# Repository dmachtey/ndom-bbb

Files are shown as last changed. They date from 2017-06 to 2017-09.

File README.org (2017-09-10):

* High density BBB domotic cape.
  - 32 opto inputs +32 opto outputs for BeagleBone Black
  - this board is intended to be used for domotics or whatever you
    want.
  - It has Push-in spring's connectors for easiness and space reduction
  - All inputs and outputs are gated though =GPIO3_15=
  - There are two more boards on this project:
    - "relay-board" is a single relay board.
    - "out-board" is a high current (10A) Mosfet Board intended for
      (soft) PWM LEDs, up to 60 volts

#+ATTR_LaTeX: :width 10cm\textwidth :options angle=0 :placement [H]
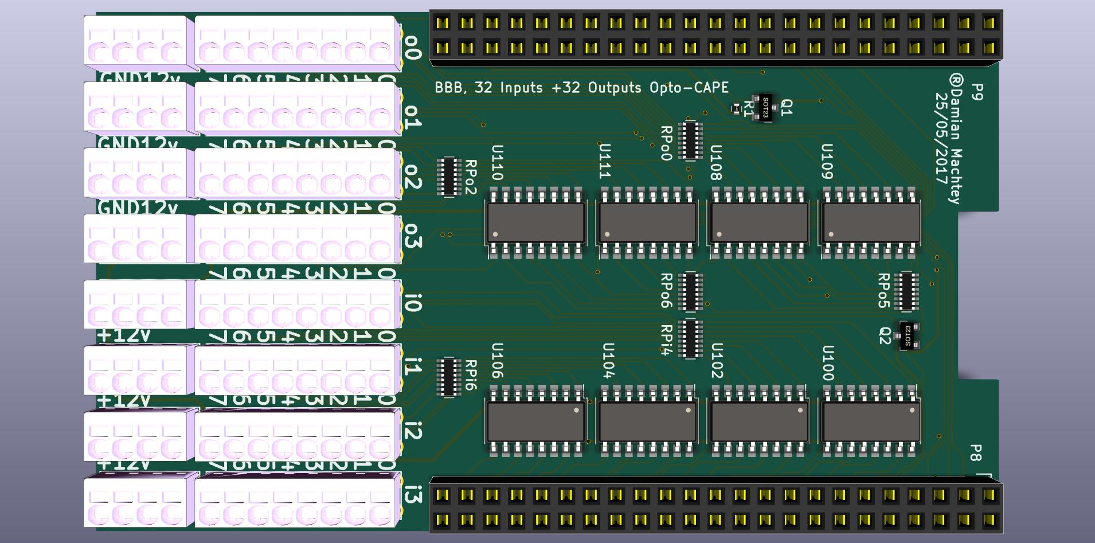
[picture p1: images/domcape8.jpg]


* Contact information
  - Damian Machtey
  - dmachtey at gmail com
* License
  - Hardware is released under [[http://creativecommons.org/licenses/by-sa/4.0/][Creative Commons Sharealike 4.0
    International]]
    
  - Software is released under GNU General Public License
    http://www.gnu.org/licenses/
  - © 2017 Damian Machtey

* Fell free to use this project
  - Just please let me know
  - and if you manufacture the board please keep my name on it.

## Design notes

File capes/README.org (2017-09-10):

* To be able to use all the 65 gpio you need to:

** Disable some capes

edit /boot/uEnv.txt and add:
#+BEGIN_EXAMPLE
         optargs=quietcapemgr.disable_partno=BB-BONELT-HDMI,BB-BONELT-HDMIN,BB-BONE-EMMC-2G
#+END_EXAMPLE

Reboot, and

if it works: you should see some thing like this:

#+BEGIN_EXAMPLE
   root@beaglebone:~# SLOTS=/sys/devices/bone_capemgr.9/slots
   root@beaglebone:~# cat $SLOTS
    0: 54:PF---
    1: 55:PF---
    2: 56:PF---
    3: 57:PF---
    4: ff:P-O-- Bone-LT-eMMC-2G,00A0,Texas Instrument,BB-BONE-EMMC-2G
    5: ff:P-O-- Bone-Black-HDMI,00A0,Texas Instrument,BB-BONELT-HDMI
    6: ff:P-O-- Bone-Black-HDMIN,00A0,Texas Instrument,BB-BONELT-HDMIN
#+END_EXAMPLE
and ther should be no "L"  before the capes lines

** Load the new cape
As an example

#+BEGIN_SRC sh
    SLOTS=/sys/devices/bone_capemgr.9/slots
    echo GPIOS-dommach > $SLOTS
#+END_SRC

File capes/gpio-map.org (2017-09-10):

# Description:
# Author: Damian Machtey
#
# Created: Tue Sep  5 15:23:36 2017 (-0300)
#
# Last-Updated: Fri Sep  8 10:53:05 2017 (-0300)
#           By: Damian Machtey
#
#

        | Address  Mode   | BBB Port | gpio number | Slot | Order | gpio     | Modee 7 | Mode | Mode    | Comment |   |   |
        |-----------------+----------+-------------+------+-------+----------+---------+------+---------+---------+---+---|
        | 0x194  0x07  // | P9_29    |         111 | -    |     - | GPIO3_15 | SPI     |      | BoardEn |         |   |   |
        | 0x038  0x27  // | P8_16    |          46 | i4   |     0 | GPIO1_14 |         |      |         |         |   |   |
        | 0x08c  0x27  // | P8_18    |          65 | i4   |     1 | GPIO2_1  |         |      |         |         |   |   |
        | 0x084  0x27  // | P8_20    |          63 | i4   |     2 | GPIO1_31 | UART4   |      |         |         |   |   |
        | 0x014  0x27  // | P8_22    |          37 | i4   |     3 | GPIO1_5  |         |      |         |         |   |   |
        | 0x010  0x27  // | P8_23    |          36 | i4   |     4 | GPIO1_4  |         |      |         |         |   |   |
        | 0x000  0x27  // | P8_25    |          32 | i4   |     5 | GPIO1_0  |         |      |         |         |   |   |
        | 0x0E0  0x27  // | P8_27    |          86 | i4   |     6 | GPIO2_22 |         |      |         |         |   |   |
        | 0x0E4  0x27  // | P8_29    |          87 | i4   |     7 | GPIO2_23 |         |      |         |         |   |   |
        | 0x0EC  0x27  // | P8_30    |          89 | i5   |     0 | GPIO2_25 |         |      |         |         |   |   |
        | 0x0E8  0x27  // | P8_28    |          88 | i5   |     1 | GPIO2_24 |         |      |         |         |   |   |
        | 0x07c  0x27  // | P8_26    |          61 | i5   |     2 | GPIO1_29 |         |      |         |         |   |   |
        | 0x004  0x27  // | P8_24    |          33 | i5   |     3 | GPIO1_1  |         |      |         |         |   |   |
        | 0x080  0x27  // | P8_21    |          62 | i5   |     4 | GPIO1_30 | UART4   |      |         |         |   |   |
        | 0x020  0x27  // | P8_19    |          22 | i5   |     5 | GPIO0_22 |         |      |         |         |   |   |
        | 0x02c  0x27  // | P8_17    |          27 | i5   |     6 | GPIO0_27 |         |      |         |         |   |   |
        | 0x03c  0x27  // | P8_15    |          47 | i5   |     7 | GPIO1_15 |         |      |         |         |   |   |
        | 0x0A0  0x27  // | P8_45    |          70 | i6   |     0 | GPIO2_6  |         |      |         |         |   |   |
        | 0x0A8  0x27  // | P8_43    |          72 | i6   |     1 | GPIO2_8  |         |      |         |         |   |   |
        | 0x0B4  0x27  // | P8_42    |          75 | i6   |     2 | GPIO2_11 |         |      |         |         |   |   |
        | 0x0BC  0x27  // | P8_40    |          77 | i6   |     3 | GPIO2_13 |         |      |         |         |   |   |
        | 0x0C0  0x27  // | P8_37    |          78 | i6   |     4 | GPIO2_14 |         |      |         |         |   |   |
        | 0x0C8  0x27  // | P8_36    |          80 | i6   |     5 | GPIO2_16 |         |      |         |         |   |   |
        | 0x0CC  0x27  // | P8_34    |          81 | i6   |     6 | GPIO2_17 |         |      |         |         |   |   |
        | 0x0DC  0x27  // | P8_32    |          11 | i6   |     7 | GPIO0_11 |         |      |         |         |   |   |
        | 0x0A4  0x27  // | P8_46    |          71 | i7   |     0 | GPIO2_7  |         |      |         |         |   |   |
        | 0x0AC  0x27  // | P8_44    |          73 | i7   |     1 | GPIO2_9  |         |      |         |         |   |   |
        | 0x0B0  0x27  // | P8_41    |          74 | i7   |     2 | GPIO2_10 |         |      |         |         |   |   |
        | 0x0B8  0x27  // | P8_39    |          76 | i7   |     3 | GPIO2_12 |         |      |         |         |   |   |
        | 0x0C4  0x27  // | P8_38    |          79 | i7   |     4 | GPIO2_15 |         |      |         |         |   |   |
        | 0x0D0  0x27  // | P8_35    |           8 | i7   |     5 | GPIO0_8  |         |      |         |         |   |   |
        | 0x0D4  0x27  // | P8_33    |           9 | i7   |     6 | GPIO0_9  |         |      |         |         |   |   |
        | 0x0D8  0x27  // | P8_31    |          10 | i7   |     7 | GPIO0_10 |         |      |         |         |   |   |
        | 0x00c  0x07  // | P8_06    |          35 | o0   |     0 | GPIO1_3  |         |      |         |         |   |   |
        | 0x008  0x07  // | P8_05    |          34 | o0   |     1 | GPIO1_2  |         |      |         |         |   |   |
        | 0x01c  0x07  // | P8_04    |          39 | o0   |     2 | GPIO1_7  |         |      |         |         |   |   |
        | 0x018  0x07  // | P8_03    |          38 | o0   |     3 | GPIO1_6  |         |      | ??      |         |   |   |
        | 0x028  0x07  // | P8_14    |          26 | o0   |     4 | GPIO0_26 |         |      |         |         |   |   |
        | 0x024  0x07  // | P8_13    |          23 | o0   |     5 | GPIO0_23 |         |      |         |         |   |   |
        | 0x030  0x07  // | P8_12    |          44 | o0   |     6 | GPIO1_12 |         |      |         |         |   |   |
        | 0x034  0x07  // | P8_11    |          45 | o0   |     7 | GPIO1_13 |         |      |         |         |   |   |
        | 0x070  0x07  // | P9_11    |          30 | o1   |     0 | GPIO0_30 |         |      |         |         |   |   |
        | 0x078  0x07  // | P9_12    |          60 | o1   |     1 | GPIO1_28 |         |      |         |         |   |   |
        | 0x074  0x07  // | P9_13    |          31 | o1   |     2 | GPIO0_31 |         |      |         |         |   |   |
        | 0x048  0x07  // | P9_14    |          50 | o1   |     3 | GPIO1_18 |         |      |         |         |   |   |
        | 0x098  0x07  // | P8_10    |          68 | o1   |     4 | GPIO2_4  |         |      |         |         |   |   |
        | 0x09c  0x07  // | P8_09    |          69 | o1   |     5 | GPIO2_5  |         |      |         |         |   |   |
        | 0x094  0x07  // | P8_08    |          67 | o1   |     6 | GPIO2_3  |         |      |         |         |   |   |
        | 0x090  0x07  // | P8_07    |          66 | o1   |     7 | GPIO2_2  |         |      |         |         |   |   |
        | 0x198  0x07  // | P9_30    |         112 | o2   |     0 | GPIO3_16 | SPI     |      |         |         |   |   |
        | 0x190  0x07  // | P9_31    |         110 | o2   |     1 | GPIO3_14 | SPI     |      |         |         |   |   |
        | 0x1b4  0x07  // | P9_41    |          20 | o2   |     2 | GPIO0_20 |         |      |         |         |   |   |
        | 0x164  0x07  // | P9_42    |           7 | o2   |     3 | GPIO0_7  |         |      |         |         |   |   |
        | 0x158  0x07  // | P9_18    |           4 | o2   |     4 | GPIO0_4  | I2C1    |      |         |         |   |   |
        | 0x15c  0x07  // | P9_17    |           5 | o2   |     5 | GPIO0_5  | I2C1    |      |         |         |   |   |
        | 0x04c  0x07  // | P9_16    |          51 | o2   |     6 | GPIO1_19 |         |      |         |         |   |   |
        | 0x040  0x07  // | P9_15    |          48 | o2   |     7 | GPIO1_16 |         |      |         |         |   |   |
        | 0x184  0x07  // | P9_24    |          15 | o3   |     0 | GPIO0_15 | UART1   | I2C1 |         |         |   |   |
        | 0x044  0x07  // | P9_23    |          49 | o3   |     1 | GPIO1_17 |         |      |         |         |   |   |
        | 0x150  0x07  // | P9_22    |           2 | o3   |     2 | GPIO0_2  | UART2   | I2C2 |         |         |   |   |
        | 0x154  0x07  // | P9_21    |           3 | o3   |     3 | GPIO0_3  | UART2   | I2C2 |         |         |   |   |
        | 0x19c  0x07  // | P9_28    |         113 | o3   |     4 | GPIO3_17 | SPI     |      |         |         |   |   |
        | 0x1a4  0x07  // | P9_27    |         115 | o3   |     5 | GPIO3_19 |         |      |         |         |   |   |
        | 0x180  0x07  // | P9_26    |          14 | o3   |     6 | GPIO0_14 | UART1   | I2C1 |         |         |   |   |
        | 0x1ac  0x07  // | P9_25    |         117 | o3   |     7 | GPIO3_21 |         |      |         |         |   |   |

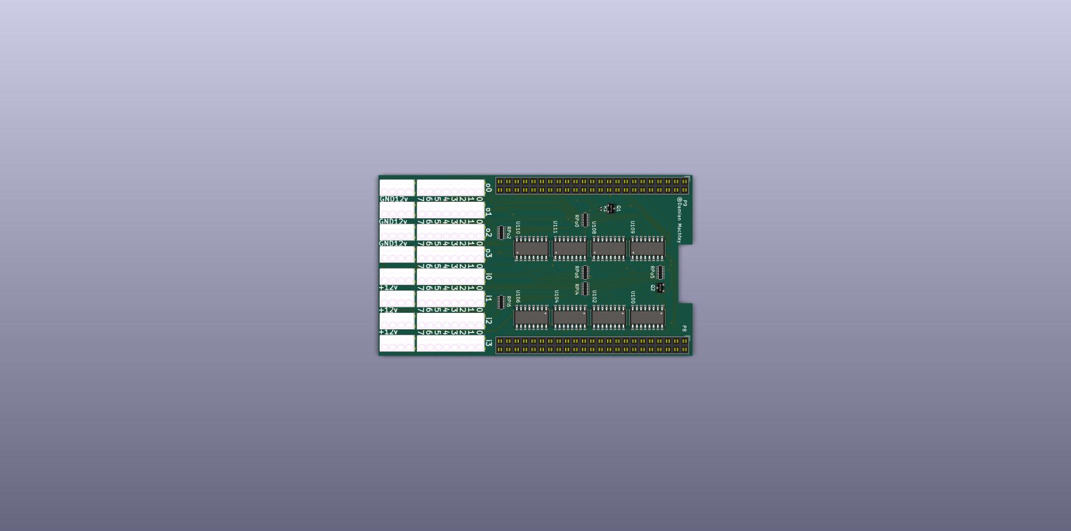
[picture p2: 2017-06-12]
images/domcape6.jpg

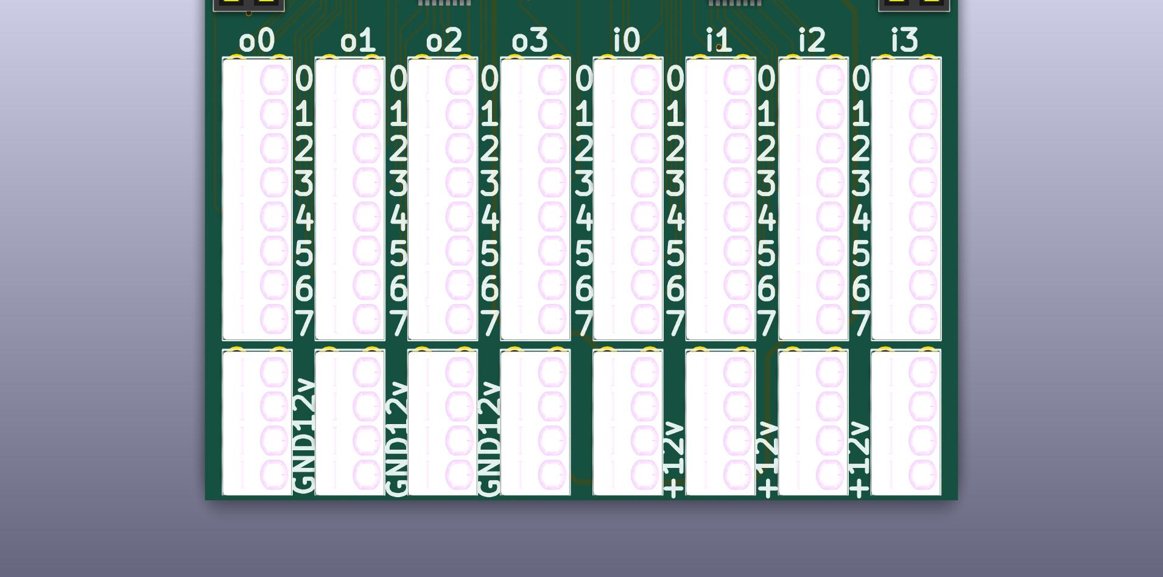
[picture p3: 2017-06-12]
images/domcape5.jpg

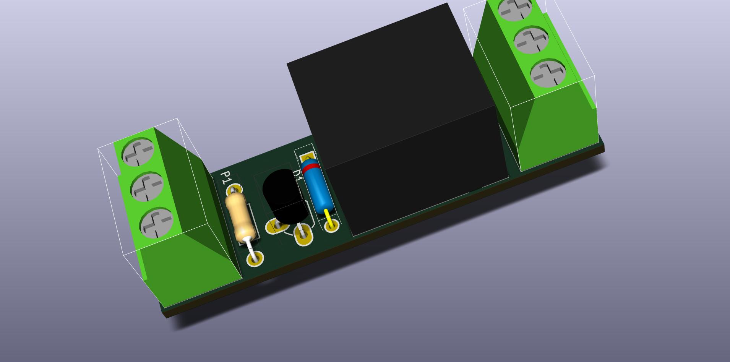
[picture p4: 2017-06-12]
images/relay-board.jpg

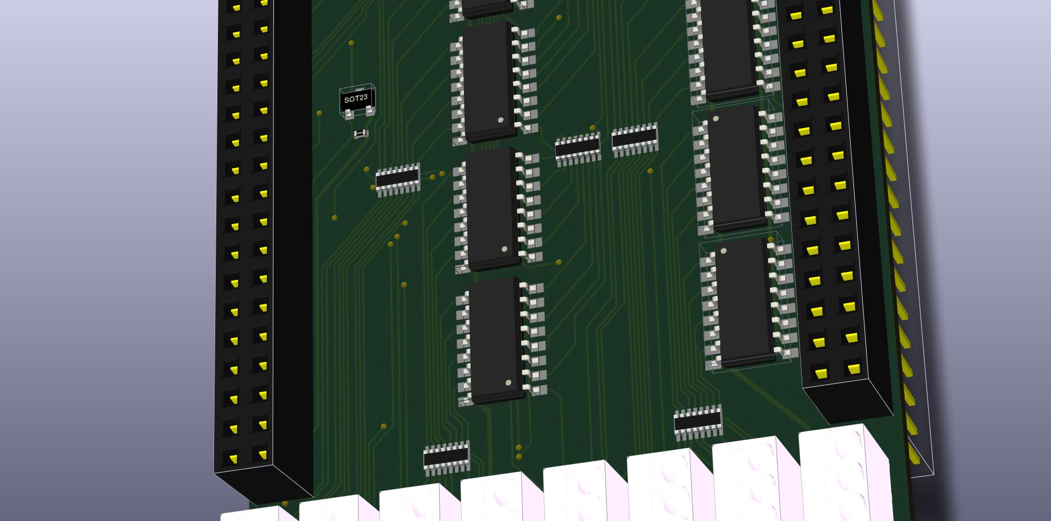
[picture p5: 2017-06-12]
images/domcape4.jpg

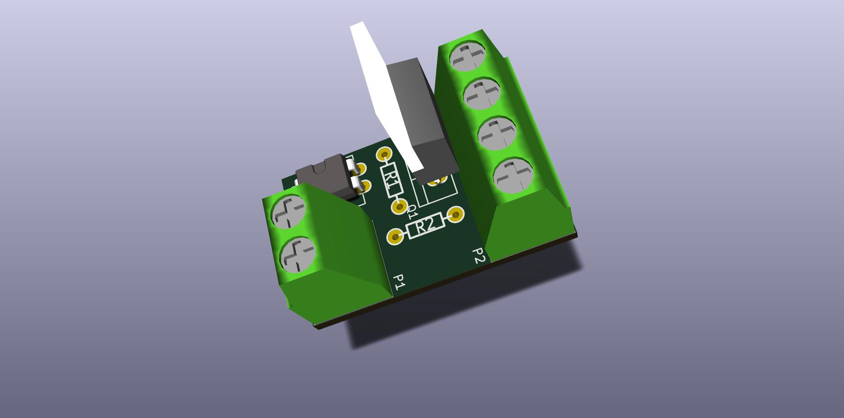
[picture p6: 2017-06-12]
images/out-board.jpg

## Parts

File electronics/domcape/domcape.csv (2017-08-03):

Reference | Value | Footprint | Datasheet
R1 | 1000G | Resistors_SMD:R_0402
P9 | BeagleBone_Black_Header
P8 | BeagleBone_Black_Header
RPo5 | MNR18ERAPJ152 | Resistors_SMD:R_Array_Convex_8x0602 | http://rohmfs.rohm.com/en/products/databook/datasheet/passive/resistor/chip_resistor_network/mnr_g.pdf
RPo6 | MNR18ERAPJ152 | Resistors_SMD:R_Array_Convex_8x0602
RPo7 | MNR18ERAPJ152 | Resistors_SMD:R_Array_Convex_8x0602
RPo8 | MNR18ERAPJ152 | Resistors_SMD:R_Array_Convex_8x0602
Px0 | Ph-1770979 | Connectors_Phoenix:Phoenix_PTSM05_4-2.5_thr
Px1 | Ph-1770979 | Connectors_Phoenix:Phoenix_PTSM05_4-2.5_thr
Px2 | Ph-1770979 | Connectors_Phoenix:Phoenix_PTSM05_4-2.5_thr
Px3 | Ph-1770979 | Connectors_Phoenix:Phoenix_PTSM05_4-2.5_thr
Px4 | Ph-1770979 | Connectors_Phoenix:Phoenix_PTSM05_4-2.5_thr
Px5 | Ph-1770979 | Connectors_Phoenix:Phoenix_PTSM05_4-2.5_thr
Px6 | Ph-1770979 | Connectors_Phoenix:Phoenix_PTSM05_4-2.5_thr
Px7 | Ph-1770979 | Connectors_Phoenix:Phoenix_PTSM05_4-2.5_thr
Po0 | Phoenix-1771017 | Connectors_Phoenix:Phoenix_PTSM05_8-2.5_thr | http://www.phoenixcontact.com/us/products/1771017/pdf
Po4 | Phoenix-1771017 | Connectors_Phoenix:Phoenix_PTSM05_8-2.5_thr | http://www.phoenixcontact.com/us/products/1771017/pdf
Po1 | Phoenix-1771017 | Connectors_Phoenix:Phoenix_PTSM05_8-2.5_thr | http://www.phoenixcontact.com/us/products/1771017/pdf
Po2 | Phoenix-1771017 | Connectors_Phoenix:Phoenix_PTSM05_8-2.5_thr | http://www.phoenixcontact.com/us/products/1771017/pdf
Po3 | Phoenix-1771017 | Connectors_Phoenix:Phoenix_PTSM05_8-2.5_thr | http://www.phoenixcontact.com/us/products/1771017/pdf
Po5 | Phoenix-1771017 | Connectors_Phoenix:Phoenix_PTSM05_8-2.5_thr | http://www.phoenixcontact.com/us/products/1771017/pdf
Po6 | Phoenix-1771017 | Connectors_Phoenix:Phoenix_PTSM05_8-2.5_thr | http://www.phoenixcontact.com/us/products/1771017/pdf
Po7 | Phoenix-1771017 | Connectors_Phoenix:Phoenix_PTSM05_8-2.5_thr | http://www.phoenixcontact.com/us/products/1771017/pdf
Q2 | SQ2303ES | Housings_SOT-23_SOT-143_TSOT-6:SOT-23 | https://www.vishay.com/docs/67023/sq2303es.pdf
Q1 | SQ2348ES | Housings_SOT-23_SOT-143_TSOT-6:SOT-23 | http://www.vishay.com/docs/63706/sq2348es.pdf
U100 | TLP291-4 | Housings_SSOP:SOP-16_4.4x10.4mm_Pitch1.27mm | http://www.mouser.com/ds/2/408/TLP291-4-204553.pdf
U101 | TLP291-4 | Housings_SSOP:SOP-16_4.4x10.4mm_Pitch1.27mm
U102 | TLP291-4 | Housings_SSOP:SOP-16_4.4x10.4mm_Pitch1.27mm
U103 | TLP291-4 | Housings_SSOP:SOP-16_4.4x10.4mm_Pitch1.27mm
U104 | TLP291-4 | Housings_SSOP:SOP-16_4.4x10.4mm_Pitch1.27mm
U105 | TLP291-4 | Housings_SSOP:SOP-16_4.4x10.4mm_Pitch1.27mm
U106 | TLP291-4 | Housings_SSOP:SOP-16_4.4x10.4mm_Pitch1.27mm
U107 | TLP291-4 | Housings_SSOP:SOP-16_4.4x10.4mm_Pitch1.27mm
U108 | TLP291-4 | Housings_SSOP:SOP-16_4.4x10.4mm_Pitch1.27mm
U109 | TLP291-4 | Housings_SSOP:SOP-16_4.4x10.4mm_Pitch1.27mm
U110 | TLP291-4 | Housings_SSOP:SOP-16_4.4x10.4mm_Pitch1.27mm
U111 | TLP291-4 | Housings_SSOP:SOP-16_4.4x10.4mm_Pitch1.27mm
U112 | TLP291-4 | Housings_SSOP:SOP-16_4.4x10.4mm_Pitch1.27mm
U113 | TLP291-4 | Housings_SSOP:SOP-16_4.4x10.4mm_Pitch1.27mm
U114 | TLP291-4 | Housings_SSOP:SOP-16_4.4x10.4mm_Pitch1.27mm
U115 | TLP291-4 | Housings_SSOP:SOP-16_4.4x10.4mm_Pitch1.27mm
RPi7 | YC248-JR-074K7L | Resistors_SMD:R_Array_Convex_8x0602
RPi6 | YC248-JR-074K7L | Resistors_SMD:R_Array_Convex_8x0602
RPi4 | YC248-JR-074K7L | Resistors_SMD:R_Array_Convex_8x0602
RPi5 | YC248-JR-074K7L | Resistors_SMD:R_Array_Convex_8x0602
RPo0 | YC248-JR-074K7L | Resistors_SMD:R_Array_Convex_8x0602
RPo1 | YC248-JR-074K7L | Resistors_SMD:R_Array_Convex_8x0602
RPo2 | YC248-JR-074K7L | Resistors_SMD:R_Array_Convex_8x0602
RPo3 | YC248-JR-074K7L | Resistors_SMD:R_Array_Convex_8x0602

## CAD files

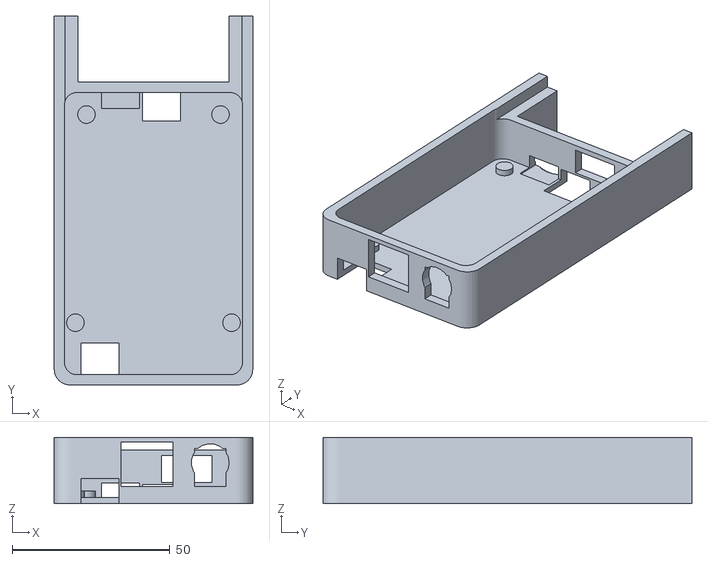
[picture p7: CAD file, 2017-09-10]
case/BBB-ndom-case.stl
63.0 x 117.0 x 21.0

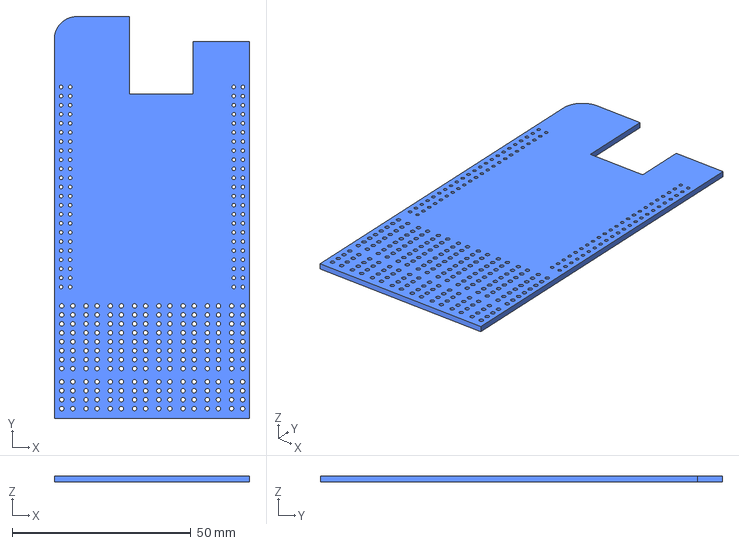
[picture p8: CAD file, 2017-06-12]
electronics/domcape/domcape.step
54.6 x 112.3 x 1.60 mm

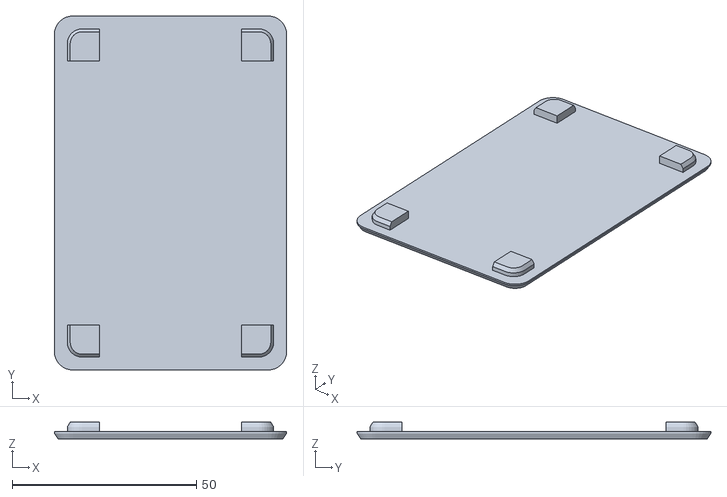
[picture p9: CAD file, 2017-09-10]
case/BeagleBoneBlack-lid.stl
63.0 x 96.0 x 4.50

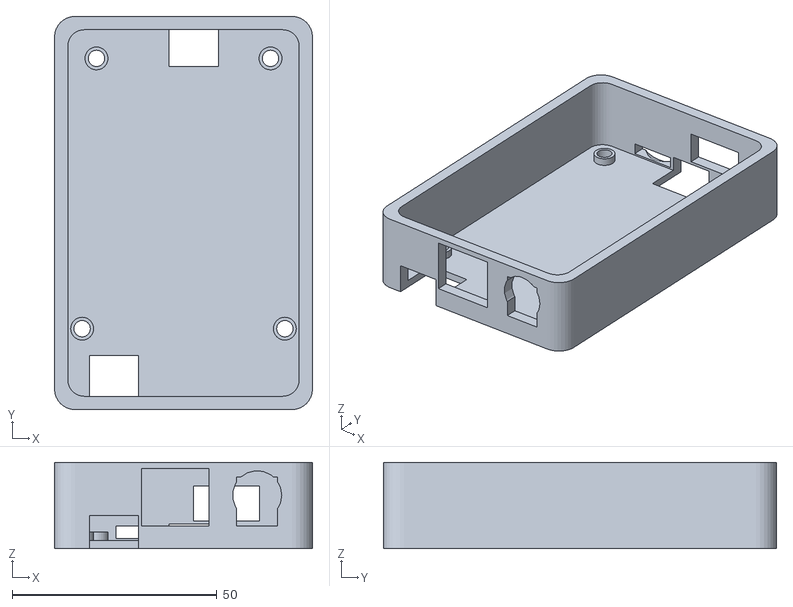
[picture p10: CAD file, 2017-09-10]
case/BeagleBoneBlack-case.stl
63.0 x 96.0 x 21.0

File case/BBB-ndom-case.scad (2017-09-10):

wall_thickness=6.5;
base_thickness=2.0;
bb_depth=20;
bb_width=56.5;
bb_height=89.5;
bb_curve_corner=10;

peg_pow_front=16.5;
peg_pow_side=3.5;

peg_sd_front=7;
peg_sd_side=7;

peg_outer_radius=2.8;
peg_inner_radius=2.0;

module RoundedBB(extra_width,extra_height,depth,curve=bb_curve_corner) {
          minkowski() {
               cube([bb_width-curve+extra_width,bb_height-curve+extra_height,depth],center=true);
               cylinder(r=curve/2, height=depth, $fn=32);
          }
}

module BeagleBox(curve=bb_curve_corner) {
     union () {
     difference() {
          RoundedBB(wall_thickness, wall_thickness, bb_depth, curve);
          translate([0,0,base_thickness])
               RoundedBB(0, 0, bb_depth, curve-2);
     }
     translate([0,55+2.5,0.5])
            cube([bb_width+wall_thickness,23,bb_depth+1],center=true);

     // wall corrections
     translate([bb_width/2+wall_thickness/2-1.5,40,0.5])
          cube([3,23,bb_depth+1],center=true);

     translate([-bb_width/2-wall_thickness/2+1.5,40,0.5])
          cube([3,23,bb_depth+1],center=true);
     }
}

difference() {
     union() {
          difference() {
               BeagleBox();

               translate([0,0,-bb_depth/2+9]) {
                    // -- Bottom End --

                    // Power connector
                    %				translate([18,-bb_height/2,2.5])
                         cube([10,10,12],center=true);
                    translate( [18,-45,4] )
                         rotate( [90,0,0] )
                         cylinder( r=6, h=9, center=true );
                    translate([18,-bb_height/2,2.5])
                         cube([10,10,12],center=true);
                    // Ethernet port
                    translate([-2,-bb_height/2,3.5])
                         cube([16.5,10,14],center=true);

                    // Mini USB (Underneath)
                    // translate([-23,-bb_height/2-5,-16])     // protruding
                    // translate([-23,-bb_height/2,-9+0.334])  // thin layer underneath
                    //	cube([10,12,base_thickness-0.3333]);
                    translate([-23,-bb_height/2-10,-10])
                         cube([12,20,9]);
                    // original mini USB, doesn't fit cable
                    % translate([-22,-bb_height/2-10,-12])
                           cube([10,20,8]);

                    // -- Top reduction Damian--
                    translate([-56/2,40,8.01-1])
                           cube([56,30,17-12]);

                    // -- End reduction
                    translate([-48/2,47.9,-11])
                         cube([48,22,20]);


                    // SD Card slot
                    translate([-6.5-4,bb_height/2,-5.0])
                         cube([12,10,5], center=true); // was 3 in z
                    // Original SD slot
                    %				translate([-6.5,bb_height/2,-5.5])
                                         cube([12,10,2], center=true);
                    // thumb depression for inserting card
                    translate([-6.5-4,bb_height/2+3.5,-5.0])
                         scale( [1,2.3,0.5] )
                         rotate( [90,0,0] )
                         cylinder( r1=7, r2=0, h=6 );
                    // HDMI port
                    translate([-6.5+3.0,bb_height/2-9,-12.0])
                         cube([12,20,9]);
                    // USB port
                    translate([10.5,bb_height/2,2.0])
                         cube([16,10,8.5],center=true);
               }
          }

          // Pegs
          translate([0,0,-bb_depth/2+9]) {
               // Pegs on "power" end
               translate([-bb_width/2+peg_pow_side,-bb_height/2+peg_pow_front,-6])
                    cylinder(r=peg_outer_radius,h=2,$fn=32,center=true);
               translate([bb_width/2-peg_pow_side,-bb_height/2+peg_pow_front,-6])
                    cylinder(r=peg_outer_radius,h=2,$fn=32,center=true);

               // Pegs on "sd card" end
               translate([-bb_width/2+peg_sd_side,bb_height/2-peg_sd_front,-6])
                    cylinder(r=peg_outer_radius,h=2,$fn=32,center=true);
               translate([bb_width/2-peg_sd_side,bb_height/2-peg_sd_front,-6])
                    cylinder(r=peg_outer_radius,h=2,$fn=32,center=true);
          }
     }
     // Drill holes through pegs and floor
//	translate([0,0,-bb_depth/2+9]) {
     // Pegs on "power" end
//		translate([-bb_width/2+peg_pow_side,-bb_height/2+peg_pow_front,-5])
//			cylinder(r=peg_inner_radius,h=10,$fn=32,center=true);
//		translate([bb_width/2-peg_pow_side,-bb_height/2+peg_pow_front,-5])
//			cylinder(r=peg_inner_radius,h=10,$fn=32,center=true);

     // Pegs on "sd card" end
//		translate([-bb_width/2+peg_sd_side,bb_height/2-peg_sd_front,-5])
//			cylinder(r=peg_inner_radius,h=10,$fn=32,center=true);
//		translate([bb_width/2-peg_sd_side,bb_height/2-peg_sd_front,-5])
//			cylinder(r=peg_inner_radius,h=10,$fn=32,center=true);
//	}
}

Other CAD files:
case/BeagleBoneBlack-case.scad
case/BeagleBoneBlack-lid.scad
electronics/domcape/domcape.FCStd

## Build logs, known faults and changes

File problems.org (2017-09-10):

# Description:
# Author: Damian Machtey
#
# Created: Sat Sep  9 12:22:26 2017 (-0300)
#
# Last-Updated: Sun Sep 10 13:53:06 2017 (-0300)
#           By: Damian Machtey
#
#

* some problems found on the board as [2017-09-09 Sat]

#+BEGIN_EXAMPLE
    root@beaglebone:~/ndom-bbb/board-test# ./board-test.py
      i0 i1 i2 i3
    0  0  0  0  0
    1  0  0  0  0
    2  1  0  0  0
    3  1  1  0  0
    4  1  1  0  0
    5  1  0  0  0
    6  0  0  0  0
    7  0  0  0  0

      a0 a1 a2 a3
    0  0  0  0  0
    1  0  0  0  0
    2  0  0  0  0
    3  0  0  0  0
    4  0  0  0  0
    5  0  0  0  0
    6  0  0  0  0
    7  0  0  0  0
#+END_EXAMPLE

    - as shown above some inputs remain high when nothing is
      connected, not even the cape. It looks like the pull-down
      resistor is not enough for some pins

      - P8_20
      - P8_21
      - P8_22
      - P8_23
      - P8_24
      - P8_25

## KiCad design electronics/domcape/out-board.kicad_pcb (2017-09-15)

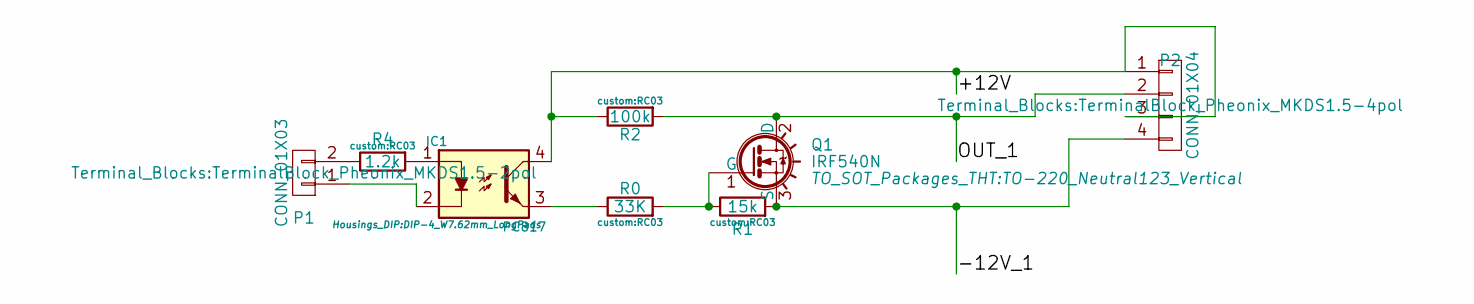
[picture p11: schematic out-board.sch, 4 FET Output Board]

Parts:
IC1: PC817; DIP-4_W7.62mm_LongPads
P1: CONN_01X03; TerminalBlock_Pheonix_MKDS1.5-2pol
P2: CONN_01X04; TerminalBlock_Pheonix_MKDS1.5-4pol
Q1: IRF540N; TO-220_Neutral123_Vertical
R0: 33K; RC03
R1: 15k; RC03
R2: 100k; RC03
R4: 1.2k; RC03

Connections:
/+12V: IC1.4, P2.1, P2.3, R2.1
/-12V_1: P2.4, Q1.3 (S), R1.2
/OUT_1: P2.2, Q1.2 (D), R2.2
unnamed: IC1.1, R4.2
unnamed: IC1.2, P1.1
unnamed: IC1.3, R0.1
unnamed: P1.2, R4.1
unnamed: Q1.1 (G), R0.2, R1.1

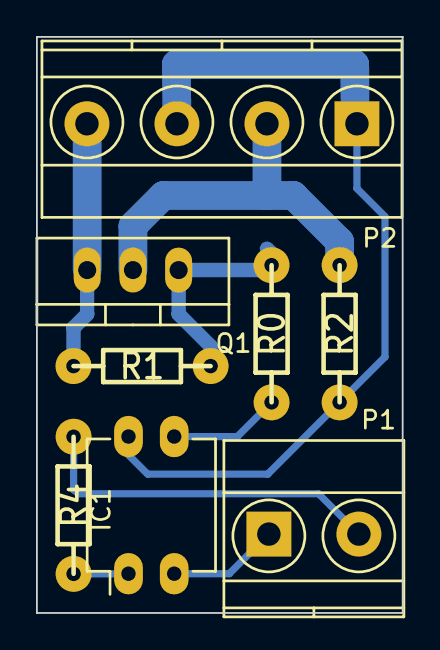
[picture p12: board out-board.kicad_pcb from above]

Board: 2 copper layers, 20.3 x 32.0 mm, 8 parts (0 on the bottom side), 8 nets.

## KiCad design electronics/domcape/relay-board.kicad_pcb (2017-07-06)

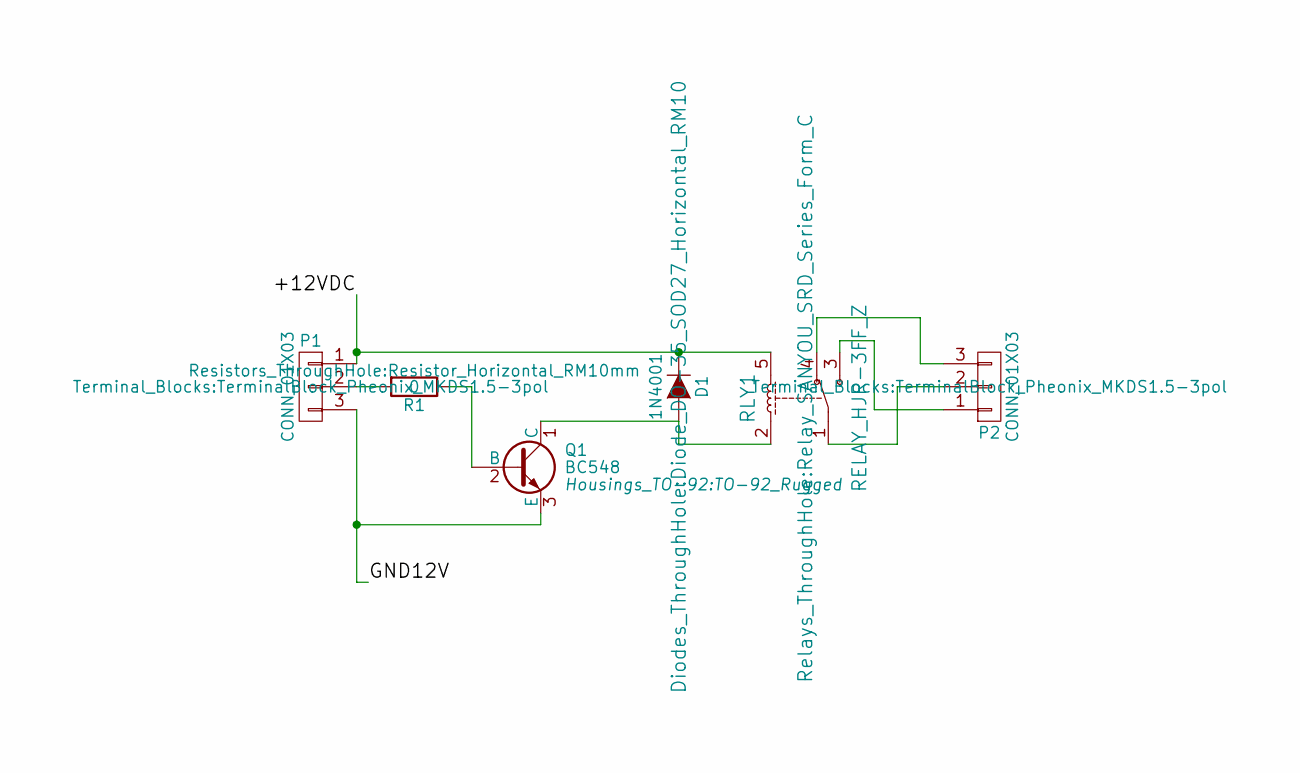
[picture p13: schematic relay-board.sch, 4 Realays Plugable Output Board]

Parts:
D1: 1N4001; Diode_DO-35_SOD27_Horizontal_RM10
P1, P2: CONN_01X03; TerminalBlock_Pheonix_MKDS1.5-3pol
Q1: BC548; TO-92_Rugged
R1: 0; Resistor_Horizontal_RM10mm
RLY1: RELAY_HJR-3FF_Z; Relay_SANYOU_SRD_Series_Form_C

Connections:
/+12VDC: D1.1 (K), P1.1, RLY1.5
/GND12V: P1.3, Q1.3 (E)
unnamed: D1.2 (A), Q1.1 (C), RLY1.2
unnamed: P1.2, R1.2
unnamed: P2.1, RLY1.3
unnamed: P2.2, RLY1.1
unnamed: P2.3, RLY1.4
unnamed: Q1.2 (B), R1.1

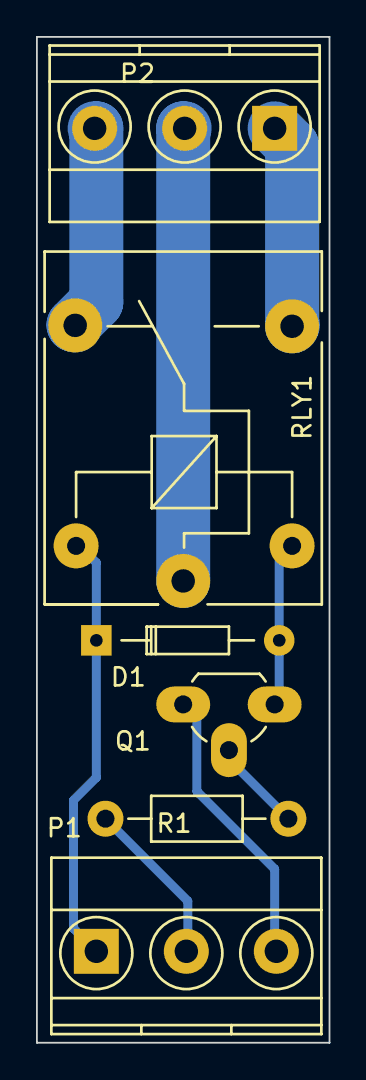
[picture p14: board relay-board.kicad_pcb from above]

Board: 2 copper layers, 16.3 x 55.9 mm, 6 parts (0 on the bottom side), 8 nets.

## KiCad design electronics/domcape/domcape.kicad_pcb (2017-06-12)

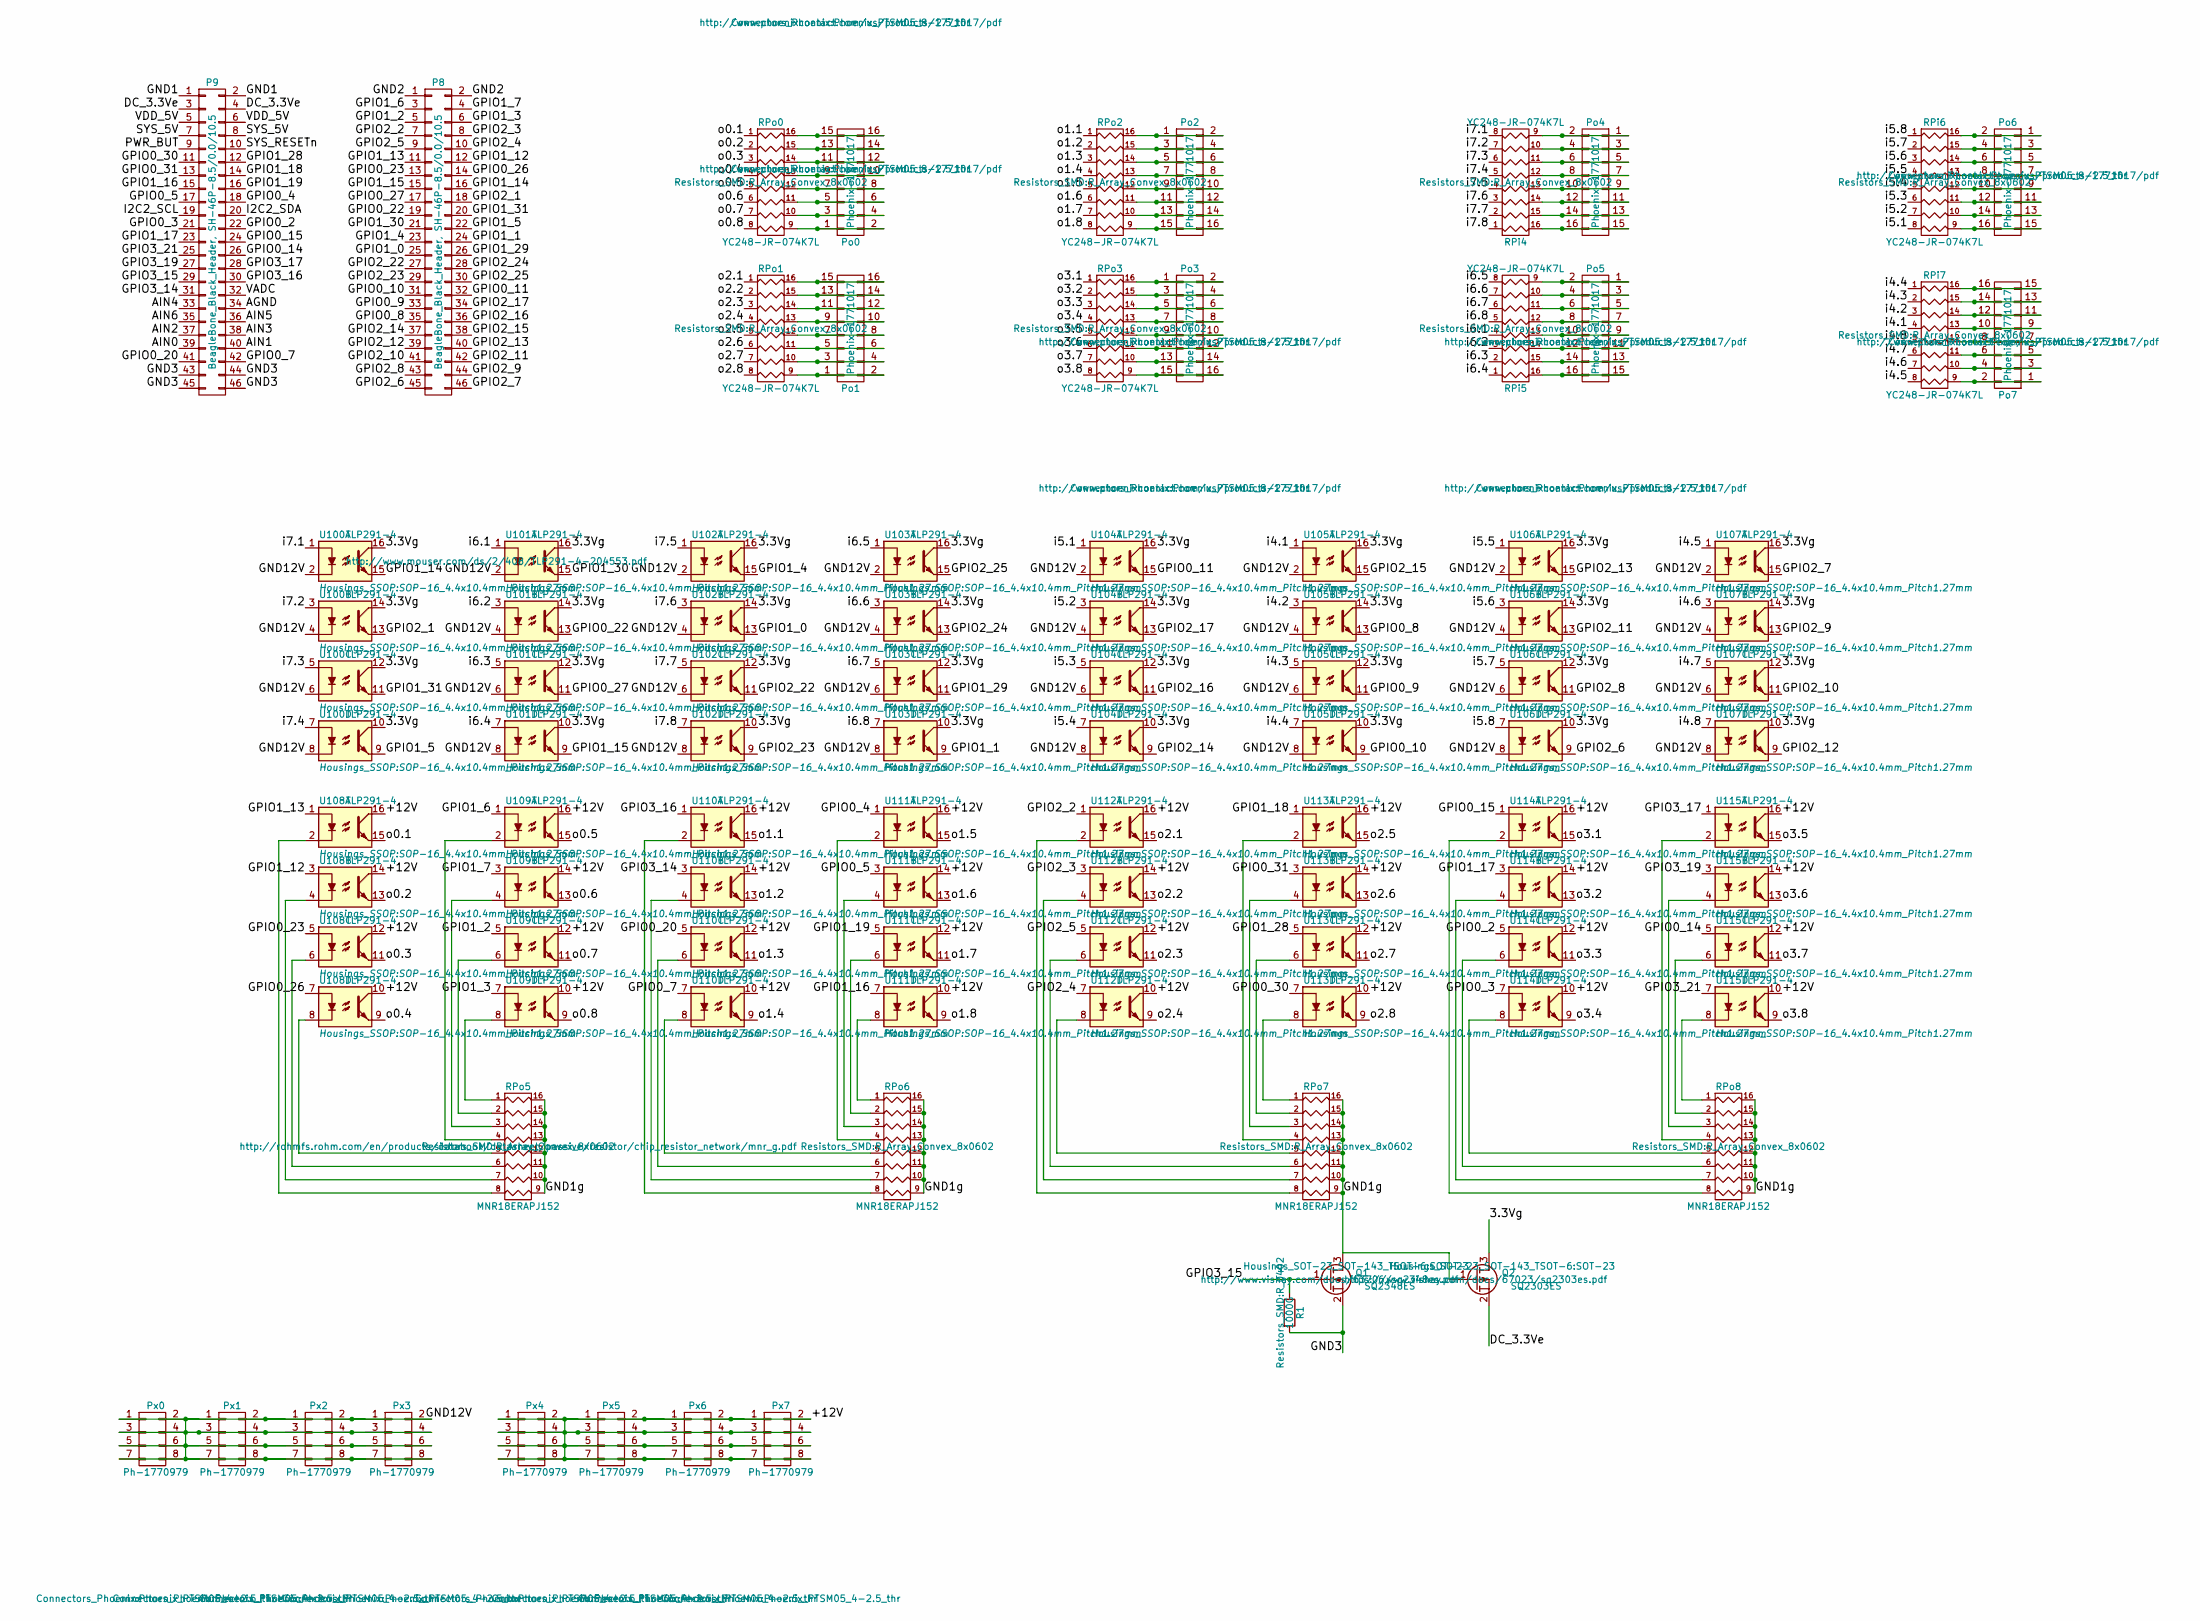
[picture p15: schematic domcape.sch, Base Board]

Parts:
P8, P9: BeagleBone_Black_Header, SH-46P-8.5/0.0/10.5
Po0, Po1, Po2, Po3, Po4, Po5, Po6, Po7: Phoenix-1771017; Phoenix_PTSM05_8-2.5_thr
Px0, Px1, Px2, Px3, Px4, Px5, Px6, Px7: Ph-1770979; Phoenix_PTSM05_4-2.5_thr
Q1: SQ2348ES; SOT-23
Q2: SQ2303ES; SOT-23
R1: 1000G; R_0402
RPi4, RPi5, RPi6, RPi7: YC248-JR-074K7L; R_Array_Convex_8x0602
RPo0, RPo1, RPo2, RPo3: YC248-JR-074K7L; R_Array_Convex_8x0602
RPo5, RPo6, RPo7, RPo8: MNR18ERAPJ152; R_Array_Convex_8x0602
U100, U101, U102, U103, U104, U105, U106, U107, U108, U109, U110, U111, U112, U113, U114, U115: TLP291-4; SOP-16_4.4x10.4mm_Pitch1.27mm

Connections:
/3.3Vg: Q2.3 (D), U100.10, U100.12, U100.14, U100.16, U101.10, U101.12, U101.14, U101.16, U102.10, U102.12, U102.14, U102.16, U103.10, U103.12, U103.14, U103.16, U104.10, U104.12, U104.14, U104.16, U105.10, U105.12, U105.14, U105.16, U106.10, U106.12, U106.14, U106.16, U107.10, U107.12, U107.14, U107.16
/+12V: Px4.1, Px4.2, Px4.3, Px4.4, Px4.5, Px4.6, Px4.7, Px4.8, Px5.1, Px5.2, Px5.3, Px5.4, Px5.5, Px5.6, Px5.7, Px5.8, Px6.1, Px6.2, Px6.3, Px6.4, Px6.5, Px6.6, Px6.7, Px6.8, Px7.1, Px7.2, Px7.3, Px7.4, Px7.5, Px7.6, Px7.7, Px7.8, U108.10, U108.12, U108.14, U108.16, U109.10, U109.12, U109.14, U109.16, U110.10, U110.12, U110.14, U110.16, U111.10, U111.12, U111.14, U111.16, U112.10, U112.12, U112.14, U112.16, U113.10, U113.12, U113.14, U113.16, U114.10, U114.12, U114.14, U114.16, U115.10, U115.12, U115.14, U115.16
/AGND: P9.34
/AIN0: P9.39
/AIN1: P9.40
/AIN2: P9.37
/AIN3: P9.38
/AIN4: P9.33
/AIN5: P9.36
/AIN6: P9.35
/DC_3.3Ve: P9.3, P9.4, Q2.2 (S)
/GND1: P9.1, P9.2
/GND1g: Q1.3 (D), Q2.1 (G), RPo5.9 (R8), RPo5.10 (R7), RPo5.11 (R6), RPo5.12 (R5), RPo5.13 (R4), RPo5.14 (R3), RPo5.15 (R2), RPo5.16 (R1), RPo6.9 (R8), RPo6.10 (R7), RPo6.11 (R6), RPo6.12 (R5), RPo6.13 (R4), RPo6.14 (R3), RPo6.15 (R2), RPo6.16 (R1), RPo7.9 (R8), RPo7.10 (R7), RPo7.11 (R6), RPo7.12 (R5), RPo7.13 (R4), RPo7.14 (R3), RPo7.15 (R2), RPo7.16 (R1), RPo8.9 (R8), RPo8.10 (R7), RPo8.11 (R6), RPo8.12 (R5), RPo8.13 (R4), RPo8.14 (R3), RPo8.15 (R2), RPo8.16 (R1)
/GND2: P8.1, P8.2
/GND3: P9.43, P9.44, P9.45, P9.46, Q1.2 (S), R1.2
/GND12V: Px0.1, Px0.2, Px0.3, Px0.4, Px0.5, Px0.6, Px0.7, Px0.8, Px1.1, Px1.2, Px1.3, Px1.4, Px1.5, Px1.6, Px1.7, Px1.8, Px2.1, Px2.2, Px2.3, Px2.4, Px2.5, Px2.6, Px2.7, Px2.8, Px3.1, Px3.2, Px3.3, Px3.4, Px3.5, Px3.6, Px3.7, Px3.8, U100.2, U100.4, U100.6, U100.8, U101.2, U101.4, U101.6, U101.8, U102.2, U102.4, U102.6, U102.8, U103.2, U103.4, U103.6, U103.8, U104.2, U104.4, U104.6, U104.8, U105.2, U105.4, U105.6, U105.8, U106.2, U106.4, U106.6, U106.8, U107.2, U107.4, U107.6, U107.8
/GPIO0_2: P9.22, U114.5
/GPIO0_3: P9.21, U114.7
/GPIO0_4: P9.18, U111.1
/GPIO0_5: P9.17, U111.3
/GPIO0_7: P9.42, U110.7
/GPIO0_8: P8.35, U105.13
/GPIO0_9: P8.33, U105.11
/GPIO0_10: P8.31, U105.9
/GPIO0_11: P8.32, U104.15
/GPIO0_14: P9.26, U115.5
/GPIO0_15: P9.24, U114.1
/GPIO0_20: P9.41, U110.5
/GPIO0_22: P8.19, U101.13
/GPIO0_23: P8.13, U108.5
/GPIO0_26: P8.14, U108.7
/GPIO0_27: P8.17, U101.11
/GPIO0_30: P9.11, U113.7
/GPIO0_31: P9.13, U113.3
/GPIO1_0: P8.25, U102.13
/GPIO1_1: P8.24, U103.9
/GPIO1_2: P8.5, U109.5
/GPIO1_3: P8.6, U109.7
/GPIO1_4: P8.23, U102.15
/GPIO1_5: P8.22, U100.9
/GPIO1_6: P8.3, U109.1
/GPIO1_7: P8.4, U109.3
/GPIO1_12: P8.12, U108.3
/GPIO1_13: P8.11, U108.1
/GPIO1_14: P8.16, U100.15
/GPIO1_15: P8.15, U101.9
/GPIO1_16: P9.15, U111.7
/GPIO1_17: P9.23, U114.3
/GPIO1_18: P9.14, U113.1
/GPIO1_19: P9.16, U111.5
/GPIO1_28: P9.12, U113.5
/GPIO1_29: P8.26, U103.11
/GPIO1_30: P8.21, U101.15
/GPIO1_31: P8.20, U100.11
/GPIO2_1: P8.18, U100.13
/GPIO2_2: P8.7, U112.1
/GPIO2_3: P8.8, U112.3
/GPIO2_4: P8.10, U112.7
/GPIO2_5: P8.9, U112.5
/GPIO2_6: P8.45, U106.9
/GPIO2_7: P8.46, U107.15
/GPIO2_8: P8.43, U106.11
/GPIO2_9: P8.44, U107.13
/GPIO2_10: P8.41, U107.11
/GPIO2_11: P8.42, U106.13
/GPIO2_12: P8.39, U107.9
/GPIO2_13: P8.40, U106.15
/GPIO2_14: P8.37, U104.9
/GPIO2_15: P8.38, U105.15
/GPIO2_16: P8.36, U104.11
/GPIO2_17: P8.34, U104.13
/GPIO2_22: P8.27, U102.11
/GPIO2_23: P8.29, U102.9
/GPIO2_24: P8.28, U103.13
/GPIO2_25: P8.30, U103.15
/GPIO3_14: P9.31, U110.3
/GPIO3_15: P9.29, Q1.1 (G), R1.1
/GPIO3_16: P9.30, U110.1
/GPIO3_17: P9.28, U115.1
/GPIO3_19: P9.27, U115.3
/GPIO3_21: P9.25, U115.7
/I2C2_SCL: P9.19
/I2C2_SDA: P9.20
/PWR_BUT: P9.9
/SYS_5V: P9.7, P9.8
/SYS_RESETn: P9.10
/VADC: P9.32
/VDD_5V: P9.5, P9.6
/i4.1: RPi7.4, U105.1
/i4.2: RPi7.3, U105.3
/i4.3: RPi7.2, U105.5
/i4.4: RPi7.1, U105.7
/i4.5: RPi7.8, U107.1
/i4.6: RPi7.7, U107.3
/i4.7: RPi7.6, U107.5
/i4.8: RPi7.5, U107.7
/i5.1: RPi6.8, U104.1
/i5.2: RPi6.7, U104.3
/i5.3: RPi6.6, U104.5
/i5.4: RPi6.5, U104.7
/i5.5: RPi6.4, U106.1
/i5.6: RPi6.3, U106.3
/i5.7: RPi6.2, U106.5
/i5.8: RPi6.1, U106.7
/i6.1: RPi5.4, U101.1
/i6.2: RPi5.3, U101.3
/i6.3: RPi5.2, U101.5
/i6.4: RPi5.1, U101.7
/i6.5: RPi5.8, U103.1
/i6.6: RPi5.7, U103.3
/i6.7: RPi5.6, U103.5
/i6.8: RPi5.5, U103.7
/i7.1: RPi4.8, U100.1
/i7.2: RPi4.7, U100.3
/i7.3: RPi4.6, U100.5
/i7.4: RPi4.5, U100.7
/i7.5: RPi4.4, U102.1
/i7.6: RPi4.3, U102.3
/i7.7: RPi4.2, U102.5
/i7.8: RPi4.1, U102.7
/o0.1: RPo0.1, U108.15
/o0.2: RPo0.2, U108.13
/o0.3: RPo0.3, U108.11
/o0.4: RPo0.4, U108.9
/o0.5: RPo0.5, U109.15
/o0.6: RPo0.6, U109.13
/o0.7: RPo0.7, U109.11
/o0.8: RPo0.8, U109.9
/o1.1: RPo2.1, U110.15
/o1.2: RPo2.2, U110.13
/o1.3: RPo2.3, U110.11
/o1.4: RPo2.4, U110.9
/o1.5: RPo2.5, U111.15
/o1.6: RPo2.6, U111.13
/o1.7: RPo2.7, U111.11
/o1.8: RPo2.8, U111.9
/o2.1: RPo1.1, U112.15
/o2.2: RPo1.2, U112.13
/o2.3: RPo1.3, U112.11
/o2.4: RPo1.4, U112.9
/o2.5: RPo1.5, U113.15
/o2.6: RPo1.6, U113.13
/o2.7: RPo1.7, U113.11
/o2.8: RPo1.8, U113.9
/o3.1: RPo3.1, U114.15
/o3.2: RPo3.2, U114.13
/o3.3: RPo3.3, U114.11
/o3.4: RPo3.4, U114.9
/o3.5: RPo3.5, U115.15
/o3.6: RPo3.6, U115.13
/o3.7: RPo3.7, U115.11
/o3.8: RPo3.8, U115.9
unnamed: Po0.1, Po0.2, RPo0.9 (R8)
unnamed: Po0.3, Po0.4, RPo0.10 (R7)
unnamed: Po0.5, Po0.6, RPo0.11 (R6)
unnamed: Po0.7, Po0.8, RPo0.12 (R5)
unnamed: Po0.9, Po0.10, RPo0.13 (R4)
unnamed: Po0.11, Po0.12, RPo0.14 (R3)
unnamed: Po0.13, Po0.14, RPo0.15 (R2)
unnamed: Po0.15, Po0.16, RPo0.16 (R1)
unnamed: Po1.1, Po1.2, RPo1.9 (R8)
unnamed: Po1.3, Po1.4, RPo1.10 (R7)
unnamed: Po1.5, Po1.6, RPo1.11 (R6)
unnamed: Po1.7, Po1.8, RPo1.12 (R5)
unnamed: Po1.9, Po1.10, RPo1.13 (R4)
unnamed: Po1.11, Po1.12, RPo1.14 (R3)
unnamed: Po1.13, Po1.14, RPo1.15 (R2)
unnamed: Po1.15, Po1.16, RPo1.16 (R1)
unnamed: Po2.1, Po2.2, RPo2.16 (R1)
unnamed: Po2.3, Po2.4, RPo2.15 (R2)
unnamed: Po2.5, Po2.6, RPo2.14 (R3)
unnamed: Po2.7, Po2.8, RPo2.13 (R4)
unnamed: Po2.9, Po2.10, RPo2.12 (R5)
unnamed: Po2.11, Po2.12, RPo2.11 (R6)
unnamed: Po2.13, Po2.14, RPo2.10 (R7)
unnamed: Po2.15, Po2.16, RPo2.9 (R8)
unnamed: Po3.1, Po3.2, RPo3.16 (R1)
unnamed: Po3.3, Po3.4, RPo3.15 (R2)
unnamed: Po3.5, Po3.6, RPo3.14 (R3)
unnamed: Po3.7, Po3.8, RPo3.13 (R4)
unnamed: Po3.9, Po3.10, RPo3.12 (R5)
unnamed: Po3.11, Po3.12, RPo3.11 (R6)
unnamed: Po3.13, Po3.14, RPo3.10 (R7)
unnamed: Po3.15, Po3.16, RPo3.9 (R8)
unnamed: Po4.1, Po4.2, RPi4.9 (R8)
unnamed: Po4.3, Po4.4, RPi4.10 (R7)
unnamed: Po4.5, Po4.6, RPi4.11 (R6)
unnamed: Po4.7, Po4.8, RPi4.12 (R5)
unnamed: Po4.9, Po4.10, RPi4.13 (R4)
unnamed: Po4.11, Po4.12, RPi4.14 (R3)
unnamed: Po4.13, Po4.14, RPi4.15 (R2)
unnamed: Po4.15, Po4.16, RPi4.16 (R1)
unnamed: Po5.1, Po5.2, RPi5.9 (R8)
unnamed: Po5.3, Po5.4, RPi5.10 (R7)
unnamed: Po5.5, Po5.6, RPi5.11 (R6)
unnamed: Po5.7, Po5.8, RPi5.12 (R5)
unnamed: Po5.9, Po5.10, RPi5.13 (R4)
unnamed: Po5.11, Po5.12, RPi5.14 (R3)
unnamed: Po5.13, Po5.14, RPi5.15 (R2)
unnamed: Po5.15, Po5.16, RPi5.16 (R1)
unnamed: Po6.1, Po6.2, RPi6.16 (R1)
unnamed: Po6.3, Po6.4, RPi6.15 (R2)
unnamed: Po6.5, Po6.6, RPi6.14 (R3)
unnamed: Po6.7, Po6.8, RPi6.13 (R4)
unnamed: Po6.9, Po6.10, RPi6.12 (R5)
unnamed: Po6.11, Po6.12, RPi6.11 (R6)
unnamed: Po6.13, Po6.14, RPi6.10 (R7)
unnamed: Po6.15, Po6.16, RPi6.9 (R8)
unnamed: Po7.1, Po7.2, RPi7.9 (R8)
unnamed: Po7.3, Po7.4, RPi7.10 (R7)
unnamed: Po7.5, Po7.6, RPi7.11 (R6)
unnamed: Po7.7, Po7.8, RPi7.12 (R5)
unnamed: Po7.9, Po7.10, RPi7.13 (R4)
unnamed: Po7.11, Po7.12, RPi7.14 (R3)
unnamed: Po7.13, Po7.14, RPi7.15 (R2)
unnamed: Po7.15, Po7.16, RPi7.16 (R1)
unnamed: RPo5.1, U109.8
unnamed: RPo5.2, U109.6
unnamed: RPo5.3, U109.4
unnamed: RPo5.4, U109.2
unnamed: RPo5.5, U108.8
unnamed: RPo5.6, U108.6
unnamed: RPo5.7, U108.4
unnamed: RPo5.8, U108.2
unnamed: RPo6.1, U111.8
unnamed: RPo6.2, U111.6
unnamed: RPo6.3, U111.4
unnamed: RPo6.4, U111.2
unnamed: RPo6.5, U110.8
unnamed: RPo6.6, U110.6
unnamed: RPo6.7, U110.4
unnamed: RPo6.8, U110.2
unnamed: RPo7.1, U113.8
unnamed: RPo7.2, U113.6
unnamed: RPo7.3, U113.4
unnamed: RPo7.4, U113.2
unnamed: RPo7.5, U112.8
unnamed: RPo7.6, U112.6
unnamed: RPo7.7, U112.4
unnamed: RPo7.8, U112.2
unnamed: RPo8.1, U115.8
unnamed: RPo8.2, U115.6
unnamed: RPo8.3, U115.4
unnamed: RPo8.4, U115.2
unnamed: RPo8.5, U114.8
unnamed: RPo8.6, U114.6
unnamed: RPo8.7, U114.4
unnamed: RPo8.8, U114.2

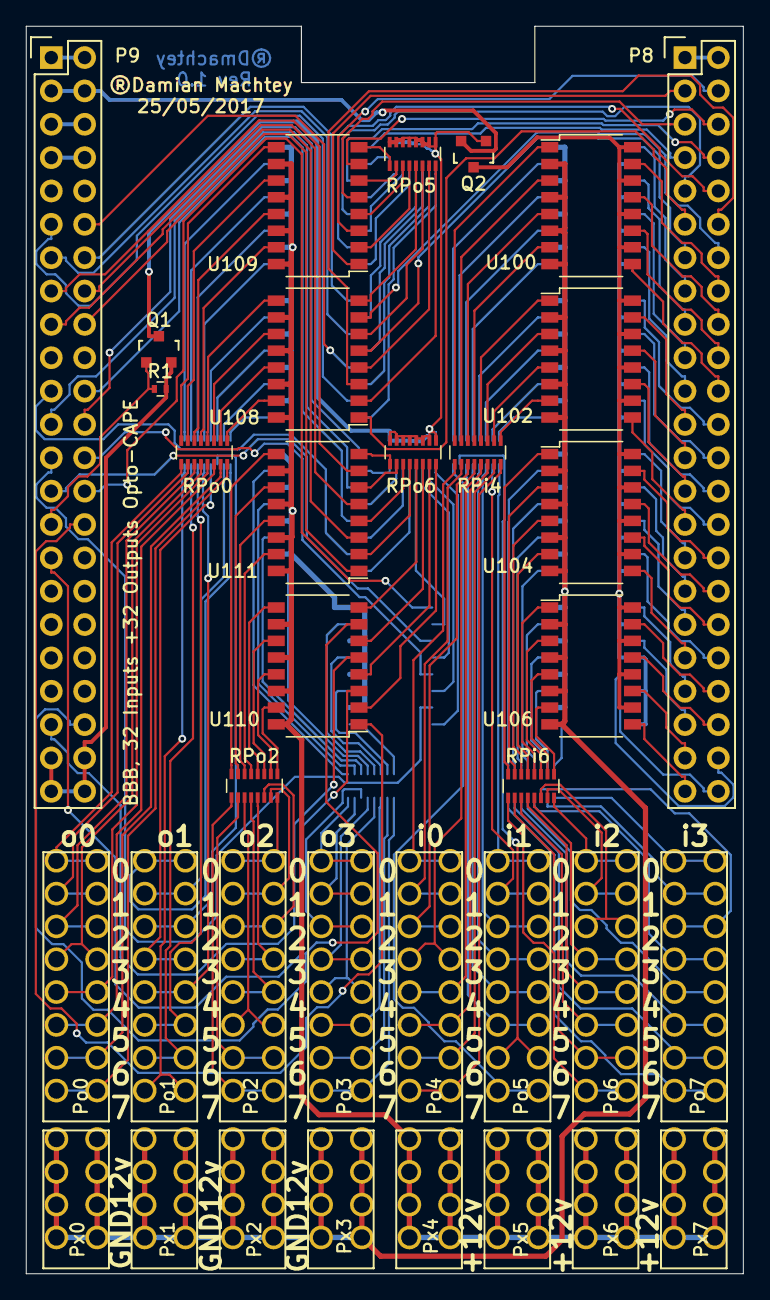
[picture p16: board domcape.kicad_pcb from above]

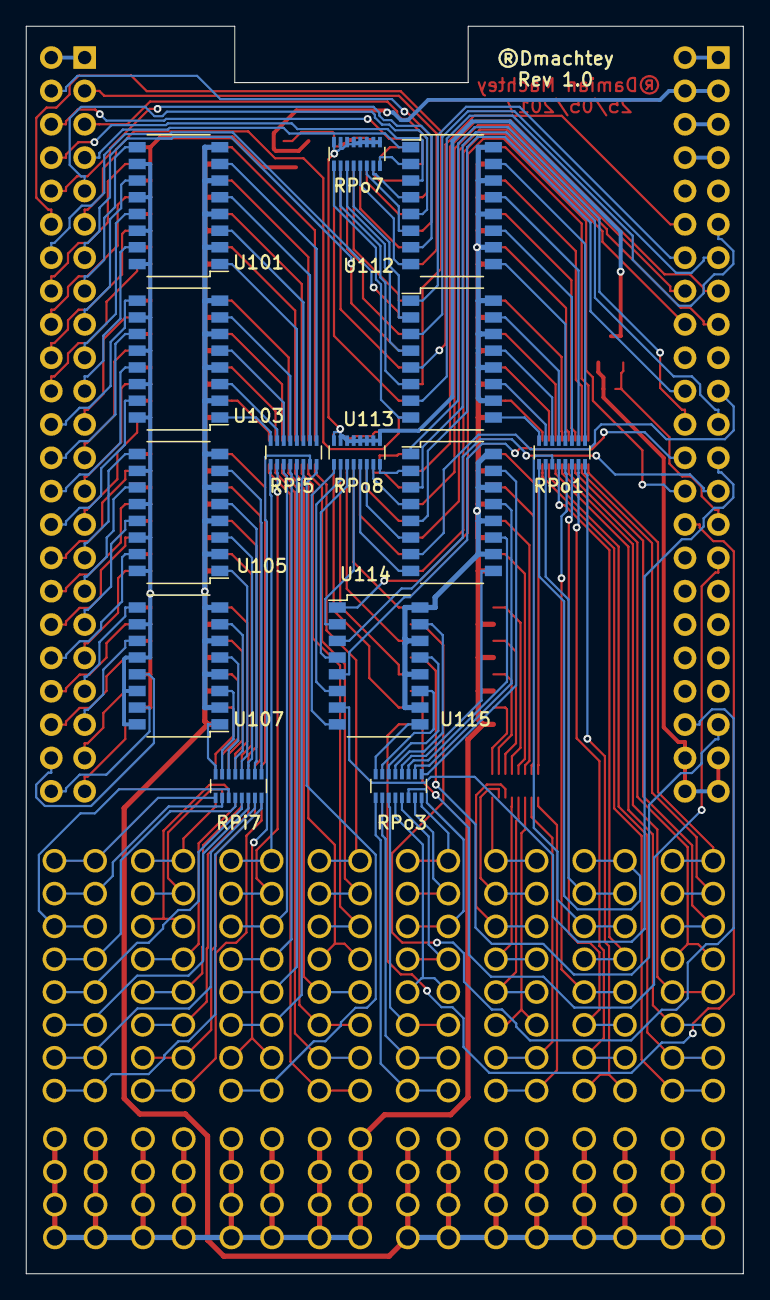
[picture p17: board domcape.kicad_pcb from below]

Board: 2 copper layers, 54.6 x 95.0 mm, 49 parts (14 on the bottom side), 235 nets.

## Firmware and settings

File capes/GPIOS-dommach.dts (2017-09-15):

// Copyright 2013
// Charles Steinkuehler <charles@steinkuehler.net>
//
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
// Modified by Damian Machtey 2015-07-02 Thu
// For home automation with Beaglebone black

/dts-v1/;
/plugin/;

/ {
    compatible = "ti,beaglebone", "ti,beaglebone-black";

    /* identification */
    part-number = "half-in-half-out";
    version = "00A0";

    /* state the resources this cape uses */
    exclusive-use =
    /*      "P8.1",     GND     */
    /*      "P8.2",     GND     */
    "P8.3",     /* emmc    */
    "P8.4",     /* emmc    */
    "P8.5",     /* emmc    */
    "P8.6",     /* emmc    */
    "P8.7",
    "P8.8",
    "P8.9",
    "P8.10",
    "P8.11",
    "P8.12",
    "P8.13",
    "P8.14",
    "P8.15",
    "P8.16",
    "P8.17",
    "P8.18",
    "P8.19",
    "P8.20",    /* emmc    */
    "P8.21",    /* emmc    */
    "P8.22",    /* emmc    */
    "P8.23",    /* emmc    */
    "P8.24",    /* emmc    */
    "P8.25",    /* emmc    */
    "P8.26",
    "P8.27",    /* hdmi    */
    "P8.28",    /* hdmi    */
    "P8.29",    /* hdmi    */
    "P8.30",    /* hdmi    */
    "P8.31",    /* hdmi    */
    "P8.32",    /* hdmi    */
    "P8.33",    /* hdmi    */
    "P8.34",    /* hdmi    */
    "P8.35",    /* hdmi    */
    "P8.36",    /* hdmi    */
    "P8.37",    /* hdmi    */
    "P8.38",    /* hdmi    */
    "P8.39",    /* hdmi    */
    "P8.40",    /* hdmi    */
    "P8.41",    /* hdmi    */
    "P8.42",    /* hdmi    */
    "P8.43",    /* hdmi    */
    "P8.44",    /* hdmi    */
    "P8.45",    /* hdmi    */
    "P8.46",    /* hdmi    */
    /*
    * "uart5",    /\* hdmi    *\/
    * "epwmss0",  /\* hdmi    *\/
    * "ehrpwm0",  /\* hdmi    *\/
    * "ecap0",    /\* hdmi    *\/
    * "epwmss1",  /\* hdmi    *\/
    * "ehrpwm1",  /\* hdmi    *\/
    * "epwmss2",  /\* hdmi    *\/
    * "ehrpwm2",  /\* hdmi    *\/
    * "ecap2",    /\* hdmi    *\/
    */

    /*      "P9.1",     GND     */
    /*      "P9.2",     GND     */
    /*      "P9.3",     3.3V    */
    /*      "P9.4",     3.3V    */
    /*      "P9.5",     VDD_5V  */
    /*      "P9.6",     VDD_5V  */
    /*      "P9.7",     SYS_5V  */
    /*      "P9.8",     SYS_5V  */
    /*      "P9.9",     PWR_BUT */
    /*      "P9.10",    RESETn  */
    "P9.11",
    "P9.12",
    "P9.13",
    "P9.14",
    "P9.15",
    "P9.16",
    "P9.17",
    "P9.18",
    /*      "P9.19",    I2C     */
    /*      "P9.20",    I2C     */
    "P9.21",
    "P9.22",
    "P9.23",
    "P9.24",
    "P9.25",
    "P9.26",
    "P9.27",
    "P9.28",
    "P9.29",
    "P9.30",
    "P9.31",
    /*      "P9.32",    VADC    */
    /*      "P9.33",    AIN4    */
    /*      "P9.34",    AGND    */
    /*      "P9.35",    AIN6    */
    /*      "P9.36",    AIN5    */
    /*      "P9.37",    AIN2    */
    /*      "P9.38",    AIN3    */
    /*      "P9.39",    AIN0    */
    /*      "P9.40",    AIN1    */
    "P9.41",
    "P9.41.1",
    "P9.42",
    "P9.42.1",
    /*      "P9.43",    GND     */
    /*      "P9.44",    GND     */
    /*      "P9.45",    GND     */
    /*      "P9.46",    GND     */

    /*
    * "uart1",
    * "uart2",
    * "uart4",
    */
    //      "uart5",    /* Conflicts with HDMI  */

    /*
    * "ehrpwm0A",
    * "ehrpwm0B",
    * "ehrpwm1A",
    * "ehrpwm1B",
    * "ehrpwm2A",
    * "ehrpwm2B",
    */

    //        "epwmss0",
    //        "ehrpwm0",
    //        "ecap0",
    //        "epwmss1",
    //        "ehrpwm1",
    //        "epwmss2",
    //        "ehrpwm2",
    //        "ecap2",

    /*
    * "i2c1",
    * "spi1",
    * "spi0",
    * "dcan0",
    * "dcan1",
    */

    "pru0",
    "pru1",
    "pruss";
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

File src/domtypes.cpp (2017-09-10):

// Filename: domtypes.cpp
//
// Description:
// Author: Damian Machtey
// Maintainer:
//
// Created: Thu Nov 10 09:17:43 2016 (-0600)
//
// Last-Updated: Tue Sep  5 17:00:45 2017 (-0300)
//           By:
//     Update #: 28

// Change Log:
//
//
// Copyright (C) 2016 Damian Machtey
//
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
//

// Code:

#include "domtypes.h"
#include "pru_data.hp"


namespace lighting{
  // array of:
  //         GPIO_SP address
  //         gpio number
  extern t_slot const slots[] = {
                                 {GPIO1_13_SP, 45  // Slot o0
                                  GPIO1_12_SP, 44
                                  GPIO0_23_SP, 23
                                  GPIO0_26_SP, 26
                                  GPIO1_6_SP, 38
                                  GPIO1_7_SP, 39
                                  GPIO1_2_SP, 34
                                  GPIO1_3_SP, 35},

                                 {GPIO3_16_SP, 112  // Slot o1
                                  GPIO3_14_SP, 110
                                  GPIO0_20_SP, 20
                                  GPIO0_7_SP, 7
                                  GPIO0_4_SP, 4
                                  GPIO0_5_SP, 5
                                  GPIO1_19_SP, 51
                                  GPIO1_16_SP, 48},

                                 {GPIO2_2_SP, 66  // Slot o2
                                  GPIO2_3_SP, 67
                                  GPIO2_5_SP, 69
                                  GPIO2_4_SP, 68
                                  GPIO1_18_SP, 50
                                  GPIO0_31_SP, 31
                                  GPIO1_28_SP, 60
                                  GPIO0_30_SP, 30},

                                 {GPIO0_15_SP, 15  // Slot o3
                                  GPIO1_17_SP, 49
                                  GPIO0_2_SP, 2
                                  GPIO0_3_SP, 3
                                  GPIO3_17_SP, 113
                                  GPIO3_19_SP, 115
                                  GPIO0_14_SP, 14
                                  GPIO3_21_SP, 117},

                                 {GPIO2_15_SP, 79  // Slot i0
                                  GPIO0_8_SP, 8
                                  GPIO0_9_SP, 9
                                  GPIO0_10_SP, 10
                                  GPIO2_7_SP, 71
                                  GPIO2_9_SP, 73
                                  GPIO2_10_SP, 74
                                  GPIO2_12_SP, 76},

                                 {GPIO0_11_SP, 11  // Slot i1
                                  GPIO2_17_SP, 81
                                  GPIO2_16_SP, 80
                                  GPIO2_14_SP, 78
                                  GPIO2_13_SP, 77
                                  GPIO2_11_SP, 75
                                  GPIO2_8_SP, 72
                                  GPIO2_6_SP, 70},

                                 {GPIO1_30_SP, 62  // Slot i2
                                  GPIO0_22_SP, 22
                                  GPIO0_27_SP, 27
                                  GPIO1_15_SP, 47
                                  GPIO2_25_SP, 89
                                  GPIO2_24_SP, 88
                                  GPIO1_29_SP, 61
                                  GPIO1_1_SP, 33},

                                 {GPIO1_14_SP, 46  // Slot i3
                                  GPIO2_1_SP, 65
                                  GPIO1_31_SP, 63
                                  GPIO1_5_SP, 37
                                  GPIO1_4_SP, 36
                                  GPIO1_0_SP, 32
                                  GPIO2_22_SP, 86
                                  GPIO2_23_SP, 87}};

}//namespace
//
// domtypes.cpp ends here

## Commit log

2017-07-06 Ploting mods
    [out-board.kicad_pcb, relay-board.kicad_pcb]
2017-08-03 add notes, and minor changes
    [domcape.csv, domcape.sch]
2017-09-10 testing, src & case
    [BBB-ndom-case.scad, BBB-ndom-case.stl, BeagleBoneBlack-case.scad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]
2017-09-10 code aesthetic
    [BBB-ndom-case.scad]
2017-09-15 out-board circuit corrections
    [out-board.kicad_pcb, out-board.sch]

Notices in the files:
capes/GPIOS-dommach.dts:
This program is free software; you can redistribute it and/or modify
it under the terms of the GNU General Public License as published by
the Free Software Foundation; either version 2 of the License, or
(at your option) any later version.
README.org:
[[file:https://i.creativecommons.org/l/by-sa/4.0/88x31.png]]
